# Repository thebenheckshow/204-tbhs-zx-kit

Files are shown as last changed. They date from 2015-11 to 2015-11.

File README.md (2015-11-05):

# 204-tbhs-zx-kit

Ben has modded many old computers into gaming portables and in this episode Ben returns to an old friend - the ZX Spectrum. He gets started by creating a schematic in eagle and designing a small PCB. Ben will conclude his journey in part 2.

Episode 204: Ben Heck's ZX Spectrum 2.0 Part 1 http://www.element14.com/community/docs/DOC-78511/l/episode-204-ben-hecks-zx-spectrum-20-part-1-episode

Episode 206: Ben Heck's ZX Spectrum 2.0 Part 2 http://www.element14.com/community/docs/DOC-78741/l/episode-206-ben-hecks-zx-spectrum-20-part-2-episode

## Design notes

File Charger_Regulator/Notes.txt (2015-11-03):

Regulators on Newark:
http://www.newark.com/Search?catalogId=15003&langId=-1&storeId=10194&gs=true&st=SC4503
http://www.newark.com/webapp/wcs/stores/servlet/Search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

Charger on Newark:
http://www.newark.com/webapp/wcs/stores/servlet/Search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

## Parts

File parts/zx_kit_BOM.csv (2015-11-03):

Part | Value | Device | Package | Description | MF | MPN | OC_FARNELL | OC_NEWARK | PACKAGE | SUPPLIER
32KRAM | CY62256LL-SNXI | CY62256LL-SNXI | SOJ28/3 | 256K (32K x 8) CMOS-Static RAM
32K_ROM | 27C256L | 27C256L | PLCC-32 | CMOS EPROM |  | AT27C256R-70JU | 1095779 | 96K6554
157 | SN74HC157D | SN74HC157D | SO16 | Multiplexer used to select address lines of video RAM
157-1 | SN74HC157D | SN74HC157D | SO16 | Multiplexer used to select address lines of video RAM
BATT |  | MA04-1 | MA04-1 | PIN HEADER |  |  | unknown | unknown
C1 | .1 | C-USC0805 | C0805 | CAPACITOR, American symbol
C2 | .1 | C-USC0805 | C0805 | CAPACITOR, American symbol
C3 | .1 | C-USC0805 | C0805 | CAPACITOR, American symbol
C4 | .1 | C-USC0805 | C0805 | CAPACITOR, American symbol
C5 | 100pf | C-USC0805 | C0805 | CAPACITOR, American symbol
C6 | .1uf | C-USC0805 | C0805 | CAPACITOR, American symbol
C7 | 22nf | C-USC0805 | C0805 | CAPACITOR, American symbol
C8 | 22nf | C-USC0805 | C0805 | CAPACITOR, American symbol
C9 | .1uf | C-USC0805 | C0805 | CAPACITOR, American symbol
C10 | .1uf | C-USC0805 | C0805 | CAPACITOR, American symbol
C11 | 10nf | C-USC0805 | C0805 | CAPACITOR, American symbol
C12 | .1uf | C-USC0805 | C0805 | CAPACITOR, American symbol
C13 | .1uf | C-USC0805 | C0805 | CAPACITOR, American symbol
C14 | 22nf | C-USC0805 | C0805 | CAPACITOR, American symbol
C15 | .1uf | C-USC0805 | C0805 | CAPACITOR, American symbol
C16 | .1uf | C-USC0805 | C0805 | CAPACITOR, American symbol
C17 | 10nf | C-USC0805 | C0805 | CAPACITOR, American symbol
C18 | 33pf | C-USC0805 | C0805 | CAPACITOR, American symbol
C19 | 33pf | C-USC0805 | C0805 | CAPACITOR, American symbol
C20 | 16pf | C-USC0805 | C0805 | CAPACITOR, American symbol
C21 | 150pf | C-USC0805 | C0805 | CAPACITOR, American symbol
C22 | 150pf | C-USC0805 | C0805 | CAPACITOR, American symbol
C23 | 22nf | C-USC0805 | C0805 | CAPACITOR, American symbol
C24 | 47nf | C-USC0805 | C0805 | CAPACITOR, American symbol
C25 | 22uf | CPOL-USB | PANASONIC_B | POLARIZED CAPACITOR, American symbol
C26 | 22nf | C-USC0805 | C0805 | CAPACITOR, American symbol
C27 | 22nf | C-USC0805 | C0805 | CAPACITOR, American symbol
C28 | 10uf | CPOL-USB | PANASONIC_B | POLARIZED CAPACITOR, American symbol
C29 | 22uf | CPOL-USB | PANASONIC_B | POLARIZED CAPACITOR, American symbol
C30 | 22uf | CPOL-USB | PANASONIC_B | POLARIZED CAPACITOR, American symbol
C31 | 10uf | CPOL-USB | PANASONIC_B | POLARIZED CAPACITOR, American symbol
C32 | 15pf | C-USC0805 | C0805 | CAPACITOR, American symbol
C33 | 10uF | CAP_CERAMIC0805 | 0805 | Ceramic Capacitors
C34 | 10uF | CAP_CERAMIC0805 | 0805 | Ceramic Capacitors
D1 |  | DIODE-SOD123 | SOD123 | DIODE
D2 |  | DIODE-SOD123 | SOD123 | DIODE
D3 |  | DIODE-SOD123 | SOD123 | DIODE
D4 |  | DIODE-SOD123 | SOD123 | DIODE
D5 |  | DIODE-SOD123 | SOD123 | DIODE
D6 |  | DIODE-SOD123 | SOD123 | DIODE
D7 |  | DIODE-SOD123 | SOD123 | DIODE
D8 |  | DIODE-SOD123 | SOD123 | DIODE
D9 |  | DIODE-SOD123 | SOD123 | DIODE
D10 |  | DIODE-SOD123 | SOD123 | DIODE
IC1 | 74LS32D | 74LS32D | SO14 | Quad 2-input OR gate
IC3 | 74AC04D | 74AC04D | SO14 | Hex INVERTER
J1 |  | USBMC32599 | MC32599
JP1 |  | AUDIO-JACKPTH | AUDIO-JACK | 3.5mm Audio Jack
JP3 | LOAD_0.1 | HEADER-1X2 | 1X02_OVAL | PIN HEADER
JP5 | BATT_IN_0.1 | HEADER-1X2 | 1X02_OVAL | PIN HEADER
K0 | DTS-6 | DTS-6 | DTS-6
K1 | DTS-6 | DTS-6 | DTS-6
K2 | DTS-6 | DTS-6 | DTS-6
K3 | DTS-6 | DTS-6 | DTS-6
K4 | DTS-6 | DTS-6 | DTS-6
K5 | DTS-6 | DTS-6 | DTS-6
K6 | DTS-6 | DTS-6 | DTS-6
K7 | DTS-6 | DTS-6 | DTS-6
K8 | DTS-6 | DTS-6 | DTS-6
K9 | DTS-6 | DTS-6 | DTS-6
KA | DTS-6 | DTS-6 | DTS-6
KB | DTS-6 | DTS-6 | DTS-6
KC | DTS-6 | DTS-6 | DTS-6
KCAPS | DTS-6 | DTS-6 | DTS-6
KD | DTS-6 | DTS-6 | DTS-6
KE | DTS-6 | DTS-6 | DTS-6
KENT | DTS-6 | DTS-6 | DTS-6
KF | DTS-6 | DTS-6 | DTS-6
KG | DTS-6 | DTS-6 | DTS-6
KH | DTS-6 | DTS-6 | DTS-6
KI | DTS-6 | DTS-6 | DTS-6
KJ | DTS-6 | DTS-6 | DTS-6
KK | DTS-6 | DTS-6 | DTS-6
KL | DTS-6 | DTS-6 | DTS-6
KM | DTS-6 | DTS-6 | DTS-6
KN | DTS-6 | DTS-6 | DTS-6
KO | DTS-6 | DTS-6 | DTS-6
KP | DTS-6 | DTS-6 | DTS-6
KQ | DTS-6 | DTS-6 | DTS-6
KR | DTS-6 | DTS-6 | DTS-6
KS | DTS-6 | DTS-6 | DTS-6
KSPACE | DTS-6 | DTS-6 | DTS-6
KSYM | DTS-6 | DTS-6 | DTS-6
KT | DTS-6 | DTS-6 | DTS-6
KU | DTS-6 | DTS-6 | DTS-6
KV | DTS-6 | DTS-6 | DTS-6
KW | DTS-6 | DTS-6 | DTS-6
KX | DTS-6 | DTS-6 | DTS-6
KY | DTS-6 | DTS-6 | DTS-6
KZ | DTS-6 | DTS-6 | DTS-6
LED1 | STAT1-ORANGE | LED0805 | CHIPLED_0805 | LED
LED2 | STAT2-GREEN | LED0805 | CHIPLED_0805 | LED
LED3 | Power-RED | LED0805 | CHIPLED_0805 | LED
Q1 | 14MHz | CRYSTALCTS406 | CTS406 | CRYSTAL |  |  | unknown | unknown
Q2 | 4.43MHz | CRYSTALHC49S | HC49/S | CRYSTAL |  |  | 1667008 | unknown
R1 | 470 | R-US_M0805 | M0805 | RESISTOR, American symbol
R2 | 470 | R-US_M0805 | M0805 | RESISTOR, American symbol
R3 | 470 | R-US_M0805 | M0805 | RESISTOR, American symbol
R4 | 470 | R-US_M0805 | M0805 | RESISTOR, American symbol
R5 | 470 | R-US_M0805 | M0805 | RESISTOR, American symbol
R6 | 470 | R-US_M0805 | M0805 | RESISTOR, American symbol
R7 | 470 | R-US_M0805 | M0805 | RESISTOR, American symbol
R8 | 470 | R-US_M0805 | M0805 | RESISTOR, American symbol
R9 | 8K2 | R-US_M0805 | M0805 | RESISTOR, American symbol
R10 | 8K2 | R-US_M0805 | M0805 | RESISTOR, American symbol
R11 | 8K2 | R-US_M0805 | M0805 | RESISTOR, American symbol
R12 | 8K2 | R-US_M0805 | M0805 | RESISTOR, American symbol
R13 | 8K2 | R-US_M0805 | M0805 | RESISTOR, American symbol
R14 | 8K2 | R-US_M0805 | M0805 | RESISTOR, American symbol
R15 | 8K2 | R-US_M0805 | M0805 | RESISTOR, American symbol
R16 | 8K2 | R-US_M0805 | M0805 | RESISTOR, American symbol
R17 | 680 | R-US_M0805 | M0805 | RESISTOR, American symbol
R18 | 680 | R-US_M0805 | M0805 | RESISTOR, American symbol
R19 | 680 | R-US_M0805 | M0805 | RESISTOR, American symbol
R20 | 680 | R-US_M0805 | M0805 | RESISTOR, American symbol
R21 | 10k | R-US_R0805 | R0805 | RESISTOR, American symbol
R22 | 680 | R-US_M0805 | M0805 | RESISTOR, American symbol
R23 | 680 | R-US_M0805 | M0805 | RESISTOR, American symbol
R24 | 680 | R-US_M0805 | M0805 | RESISTOR, American symbol
R25 | 330 | R-US_M0805 | M0805 | RESISTOR, American symbol
R26 | 10k | R-US_R0805 | R0805 | RESISTOR, American symbol
R27 | 10k | R-US_R0805 | R0805 | RESISTOR, American symbol
R28 | 10k | R-US_R0805 | R0805 | RESISTOR, American symbol
R29 | 10k | R-US_R0805 | R0805 | RESISTOR, American symbol
R30 | 1k | R-US_R0805 | R0805 | RESISTOR, American symbol
R31 | 180 | R-US_R0805 | R0805 | RESISTOR, American symbol
R32 | 1k | R-US_R0805 | R0805 | RESISTOR, American symbol
R33 | 470 | R-US_R0805 | R0805 | RESISTOR, American symbol
R34 | 150 | RESISTOR0805 | 0805 | Resistors
R35 | 10k | R-US_R0805 | R0805 | RESISTOR, American symbol
R36 | 680 | R-US_R0805 | R0805 | RESISTOR, American symbol
R37 | 1k | R-US_R0805 | R0805 | RESISTOR, American symbol
R38 | 10k | R-US_R0805 | R0805 | RESISTOR, American symbol
R39 | 10k | R-US_R0805 | R0805 | RESISTOR, American symbol
R40 | 470 | R-US_R0805 | R0805 | RESISTOR, American symbol
R41 | 1k | R-US_R0805 | R0805 | RESISTOR, American symbol
R42 | 1k | R-US_R0805 | R0805 | RESISTOR, American symbol
R43 | 1k | R-US_R0805 | R0805 | RESISTOR, American symbol
R44 | 1k | R-US_R0805 | R0805 | RESISTOR, American symbol
R45 | 5k1 | R-US_R0805 | R0805 | RESISTOR, American symbol
R46 | 3k | R-US_R0805 | R0805 | RESISTOR, American symbol
R47 | 1k | R-US_R0805 | R0805 | RESISTOR, American symbol
R48 | 1k | R-US_R0805 | R0805 | RESISTOR, American symbol
R49 | 1k | R-US_R0805 | R0805 | RESISTOR, American symbol
R50 | 1k | R-US_R0805 | R0805 | RESISTOR, American symbol
R51 | 10K | R-US_R0805 | R0805 | RESISTOR, American symbol
R52 | 15 | R-US_R0805 | R0805 | RESISTOR, American symbol
R53 | 2k2 | R-US_R0805 | R0805 | RESISTOR, American symbol
R54 | 2k2 | R-US_R0805 | R0805 | RESISTOR, American symbol
R55 | 390 | R-US_R0805 | R0805 | RESISTOR, American symbol
R56 | 4k7 | R-US_R0805 | R0805 | RESISTOR, American symbol
R57 | 2k2 | R-US_R0805 | R0805 | RESISTOR, American symbol
R58 | 10k | R-US_R0805 | R0805 | RESISTOR, American symbol
R59 | 220k | R-US_M0805 | M0805 | RESISTOR, American symbol
R60 | 1k5 | R-US_M0805 | M0805 | RESISTOR, American symbol
R61 | 10k | R-US_M0805 | M0805 | RESISTOR, American symbol
R62 | 1k | R-US_M0805 | M0805 | RESISTOR, American symbol
R63 | 150 | RESISTOR0805 | 0805 | Resistors
R64 | 470 | R-US_R0805 | R0805 | RESISTOR, American symbol
R65 | 15 | R-US_R1210 | R1210 | RESISTOR, American symbol
R66 | 150 | RESISTOR0805 | 0805 | Resistors
R67 | PROG | RESISTOR_DUAL | 0805-THM | Flip Flop resistor
R68 | 10K/THERM | R-US_FLIPFLOP | 0805-THM | RESISTOR, American symbol
REGS |  | MA04-1 | MA04-1 | PIN HEADER |  |  | unknown | unknown
ROMS |  | PINHD-1X3 | 1X03 | PIN HEADER
RST | DTS-6 | DTS-6 | DTS-6
RT1 | 1K | R-US_R0805 | R0805 | RESISTOR, American symbol
RT2 | 150K | R-US_R0805 | R0805 | RESISTOR, American symbol
SPKR |  | PINHD-1X2 | 1X02 | PIN HEADER
T1 | BC847 | BC847 | SOT23 | NPN TRANSISTOR
T2 | 4401 | MMBT4401LT1-NPN-SOT23-BEC | SOT23-BEC | NPN Transistror
T3 | 4401 | MMBT4401LT1-NPN-SOT23-BEC | SOT23-BEC | NPN Transistror
T4 | BC847 | BC847 | SOT23 | NPN TRANSISTOR
T5 | 4401 | MMBT4401LT1-NPN-SOT23-BEC | SOT23-BEC | NPN Transistror
T6 | 4401 | MMBT4401LT1-NPN-SOT23-BEC | SOT23-BEC | NPN Transistror
T7 | 4401 | MMBT4401LT1-NPN-SOT23-BEC | SOT23-BEC | NPN Transistror
U$1 | MC74HC574A | MC74HC574A | SO20W | Octal 3-State Noninverting D Flip Flop
U$2 | LM1889 | LM1889 | SOCKET-18 | LM1889 TV Video Modulator
U$3 | MS12ASW30_01 | MS12ASW30_01 | MS12ASG30_01
U1 | MCP73833-FCI/UN | MCP73833-FCI/UN | SOP50P490X110-10N | LI-ION/LI-POLY CONTROLLERS |  | MCP73833-FCI/UN | 1605576 | 88K5666 | MSOP10 | Microchip
ULA |  | ZXULA | DIL40 | ZX Spectrum Custom ULA
ULA_RAM | CY62256LL-SNXI | CY62256LL-SNXI | SOJ28/3 | 256K (32K x 8) CMOS-Static RAM
VID |  | PINHD-1X2 | 1X02 | PIN HEADER
VPOW |  | PINHD-1X2 | 1X02 | PIN HEADER
Z80A |  | Z80CPU | DIL40 | Z80 FAMILY DEVICE

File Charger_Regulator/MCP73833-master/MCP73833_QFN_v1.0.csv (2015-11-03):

Check | Qty | Value | Device | Package | Parts | Description
 | 1 | MCP73833T-AMI/MF | MCP73833DFN | DFN10_3X3MM | U1 | Lithium-Polymer/Lithium-Ion Battery Charger [Part No.]
 | 4 | MOUNTINGHOLE2.0 | MOUNTINGHOLE2.0 | MOUNTINGHOLE_2.0_PLATED | U$11, U$16, U$18, U$19 | Mounting Hole
x | 1 | 150K | R-US_R0805 | R0805 | RT2 | RESISTOR, American symbol
x | 1 | 1K | R-US_R0805 | R0805 | RT1 | RESISTOR, American symbol
x | 1 | 10K/THERM | R-US_FLIPFLOP | 0805-THM | R7 | RESISTOR, American symbol
x | 1 | PROG | RESISTOR_DUAL | 0805-THM | R4 | Flip Flop resistor
x | 3 | 150 | RESISTOR0805 | 805 | R1, R2, R3 | Resistors
UK | 1 | Power-RED | LED0805 | CHIPLED_0805 | LED3 | LED
UK | 1 | STAT2-GREEN | LED0805 | CHIPLED_0805 | LED2 | LED
UK | 1 | STAT1-ORANGE | LED0805 | CHIPLED_0805 | LED1 | LED
 | 1 | STAT | HEADER-1X2 | 1X02_OVAL | JP6 | PIN HEADER
 | 1 | BATT_IN_0.1 | HEADER-1X2 | 1X02_OVAL | JP5 | PIN HEADER
 | 1 | LOAD_0.1 | HEADER-1X2 | 1X02_OVAL | JP3 | PIN HEADER
 | 2 | FIDUCIAL1.5X3 | FIDUCIAL1X2.5 | FIDUCIAL-1X2.5 | JP2, JP4 | Fiducial Alignment Points
 | 1 | PWR_IN_0.1 | HEADER-1X2 | 1X02_OVAL | JP1 | PIN HEADER
 | 1 | LOAD_JST | JST_2PIN | JSTPH2 | CN3 | JST 2-Pin Right-Angle Connector
 | 1 | BATT_IN_JST | JST_2PIN | JSTPH2 | CN2 | JST 2-Pin Right-Angle Connector
 | 1 | USB | USBMINIBLARGE | USB-MINIB_LARGER | CN1 | USB Connectors
 | 2 | 10uF | CAP_CERAMIC0805 | 805 | C1, C2 | Ceramic Capacitors

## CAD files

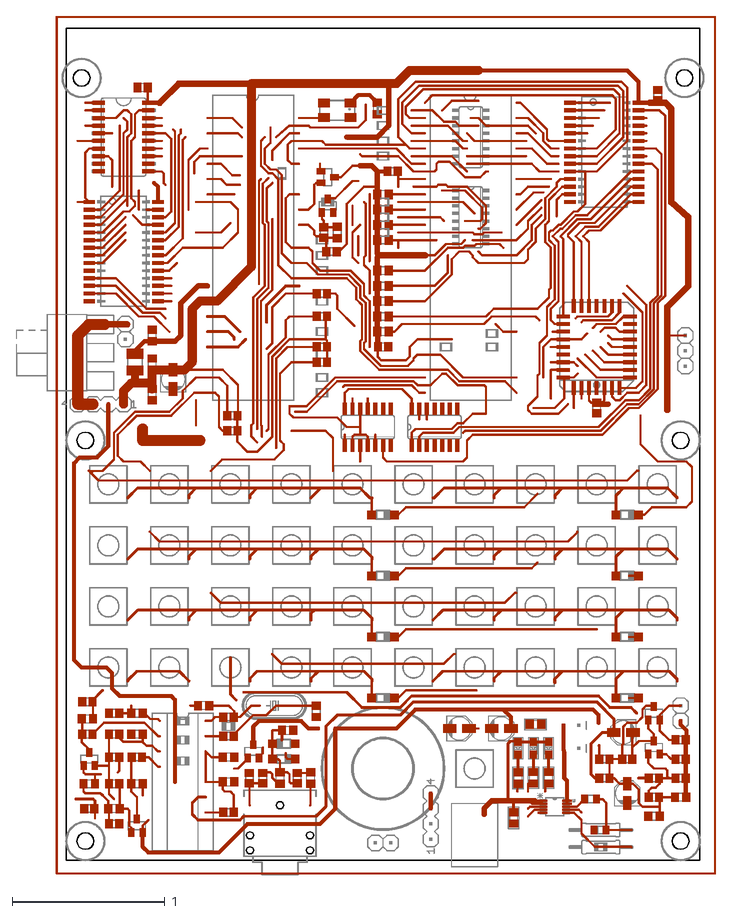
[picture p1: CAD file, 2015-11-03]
Board/zx_kit3.dxf
4.58 x 5.63

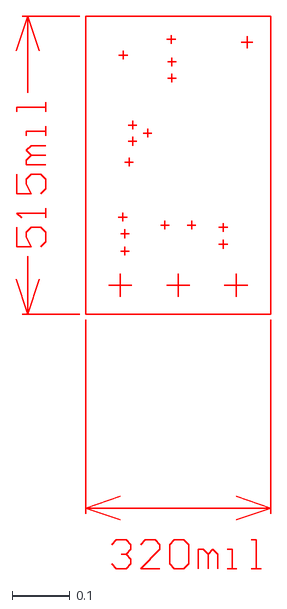
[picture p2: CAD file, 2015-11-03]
Charger_Regulator/12VRegulator/reg10a01-drill.dxf
0.44 x 0.955

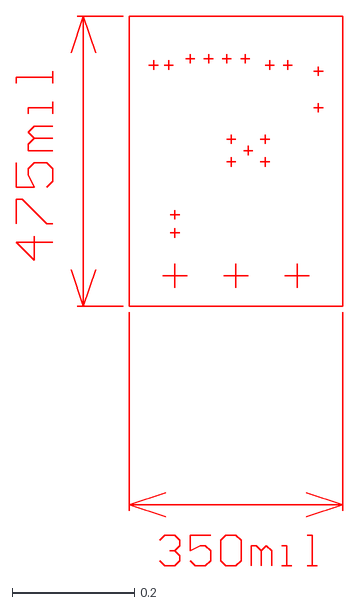
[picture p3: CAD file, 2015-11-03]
Charger_Regulator/5VRegulator/reg09a01-drill.dxf
0.535 x 0.9

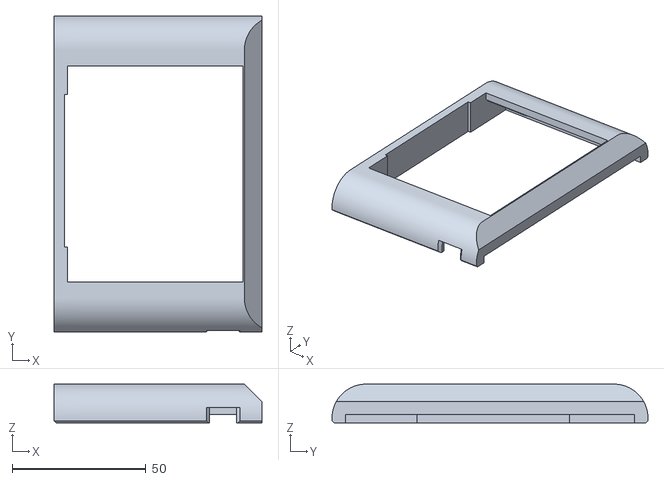
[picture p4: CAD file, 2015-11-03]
Enclosure/STL/front LCD riser.stl
77.6 x 118.1 x 14.5

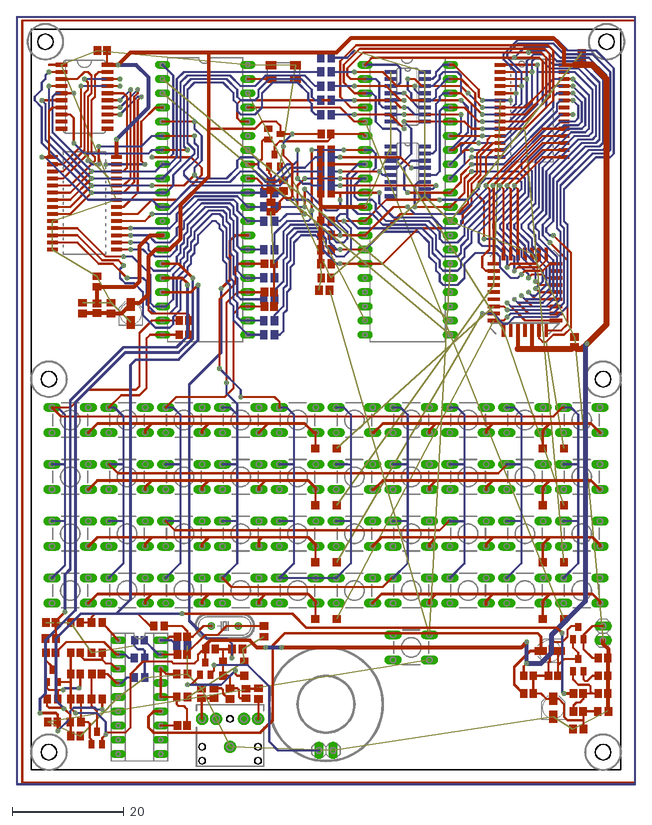
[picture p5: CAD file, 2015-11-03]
Enclosure/zx_kit2.dxf
110.8 x 137.5

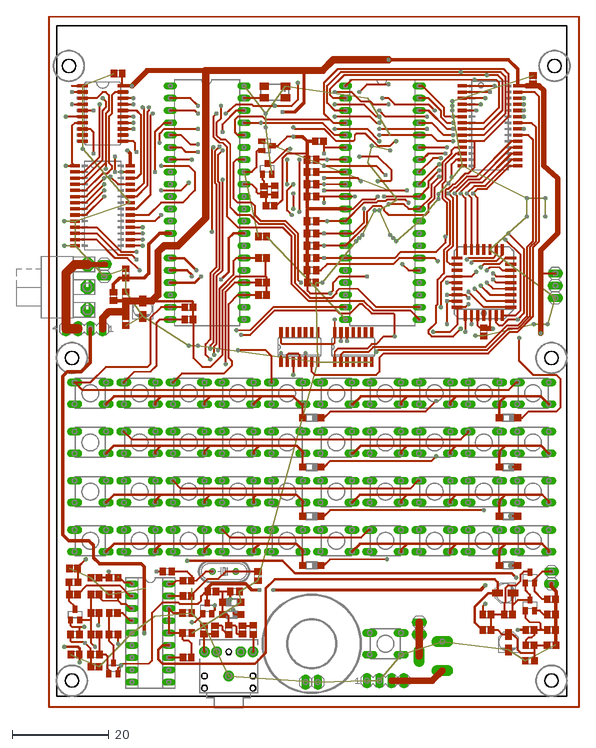
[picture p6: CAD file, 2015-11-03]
Board/zx_kit2.dxf
116.5 x 143.0

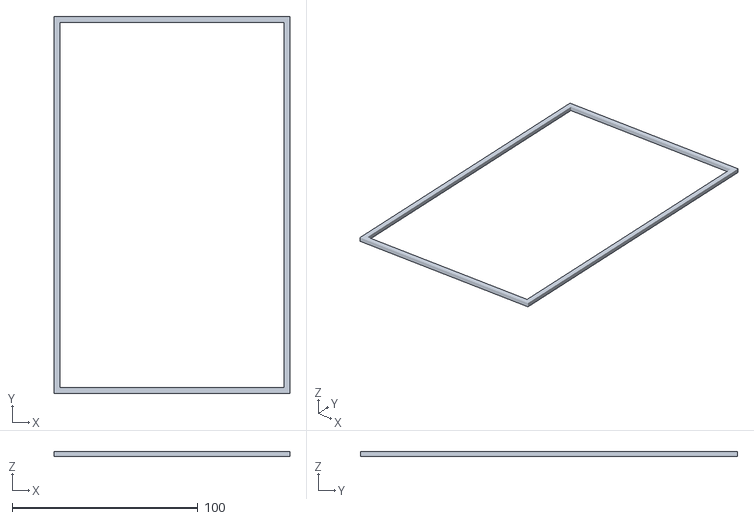
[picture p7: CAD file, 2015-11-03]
Enclosure/STL/wrecktangle.stl
127.0 x 203.2 x 2.54

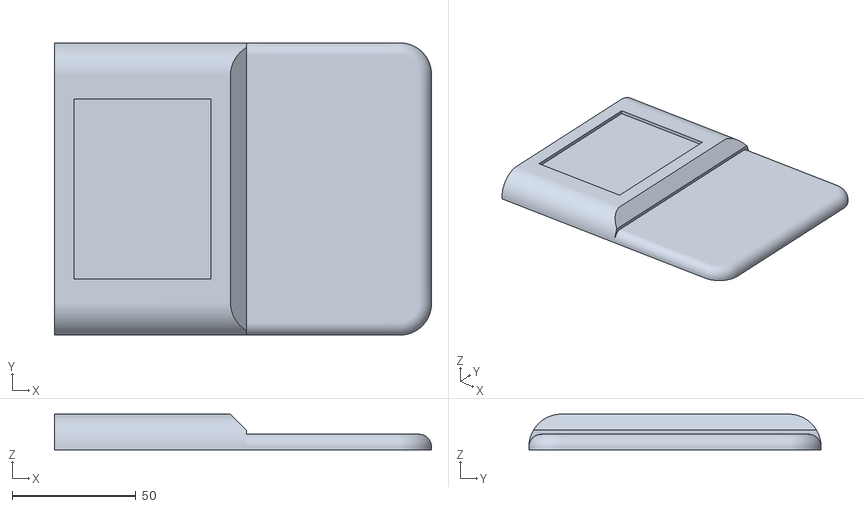
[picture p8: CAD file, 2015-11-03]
Enclosure/STL/front test.stl
152.4 x 118.1 x 14.5

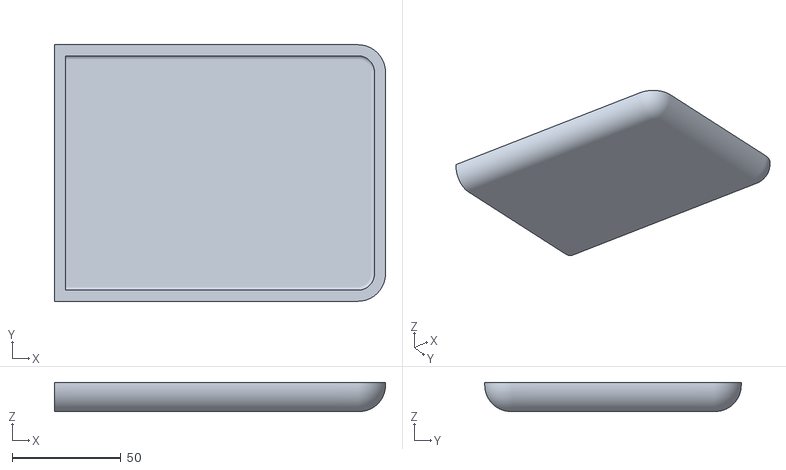
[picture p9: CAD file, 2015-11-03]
Enclosure/STL/back test.stl
152.4 x 118.1 x 13.4

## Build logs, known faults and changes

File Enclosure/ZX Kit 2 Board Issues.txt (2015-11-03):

PROBLEM: MREQ net labeled "MREQL" on CPU/ULA but "MREQ" on OR gate.
RESULT: Missing connection between CPU and OR gate on board casuing upper RAM conflict
SOLUTION: Bridge MREQ from CPU to OR gate.

PROBLEM: IORQ on CPU not connected to anything.
RESULT: Can't read keyboard from ULA (and would cause other issues too)
SOLUTION: Added a 470 ohm resister and wire between CPU's IOREQ and ULA's IOREQ (rest of circuit was placed correctly just missed this connection)

PROBLEM: INTL on ULA not connected to anything.
RESULT: System doesn't work
SOLUTION: Added a 470 ohm resister and wire between CPU's INT and ULA's INT

PROBLEM: Jumbled text on screen as a result of address bus conflict
SOLUTION: Between the MUX and ULA, use 680 ohm resisters instead of 330 (470 may work as well)

PROBLEM: ROM CE not connected to anything
RESULT: ROM doesn't work right.
SOLUTION:
OR the CPU's MREQ and the ULA's ROM_CS (through 600 ohm resistor) together, send result to ROM CE
Connect ROM_OE to CPU's READ instead of ROM_CS (move the resistor) 

NEED TO CHECK TAPE LOADING NEXT!

NEED TO ADD / CHANGE:

DONE - Remove 2k pullup on CASS/SPEAKER line to enable modern "tape" loading

DONE - Move (2) 10k resisters out from under ULA!

DONE - 15pf cap on ground side of 14MHz crystal

DONE - 1/2 watt 15 ohm thick film resistor for ULA VCC SMD case style 1210

DONE - 10uf ELEC cap on reset button for system start

DONE - ELEC CAP on lower 5v rail for speaker compensation

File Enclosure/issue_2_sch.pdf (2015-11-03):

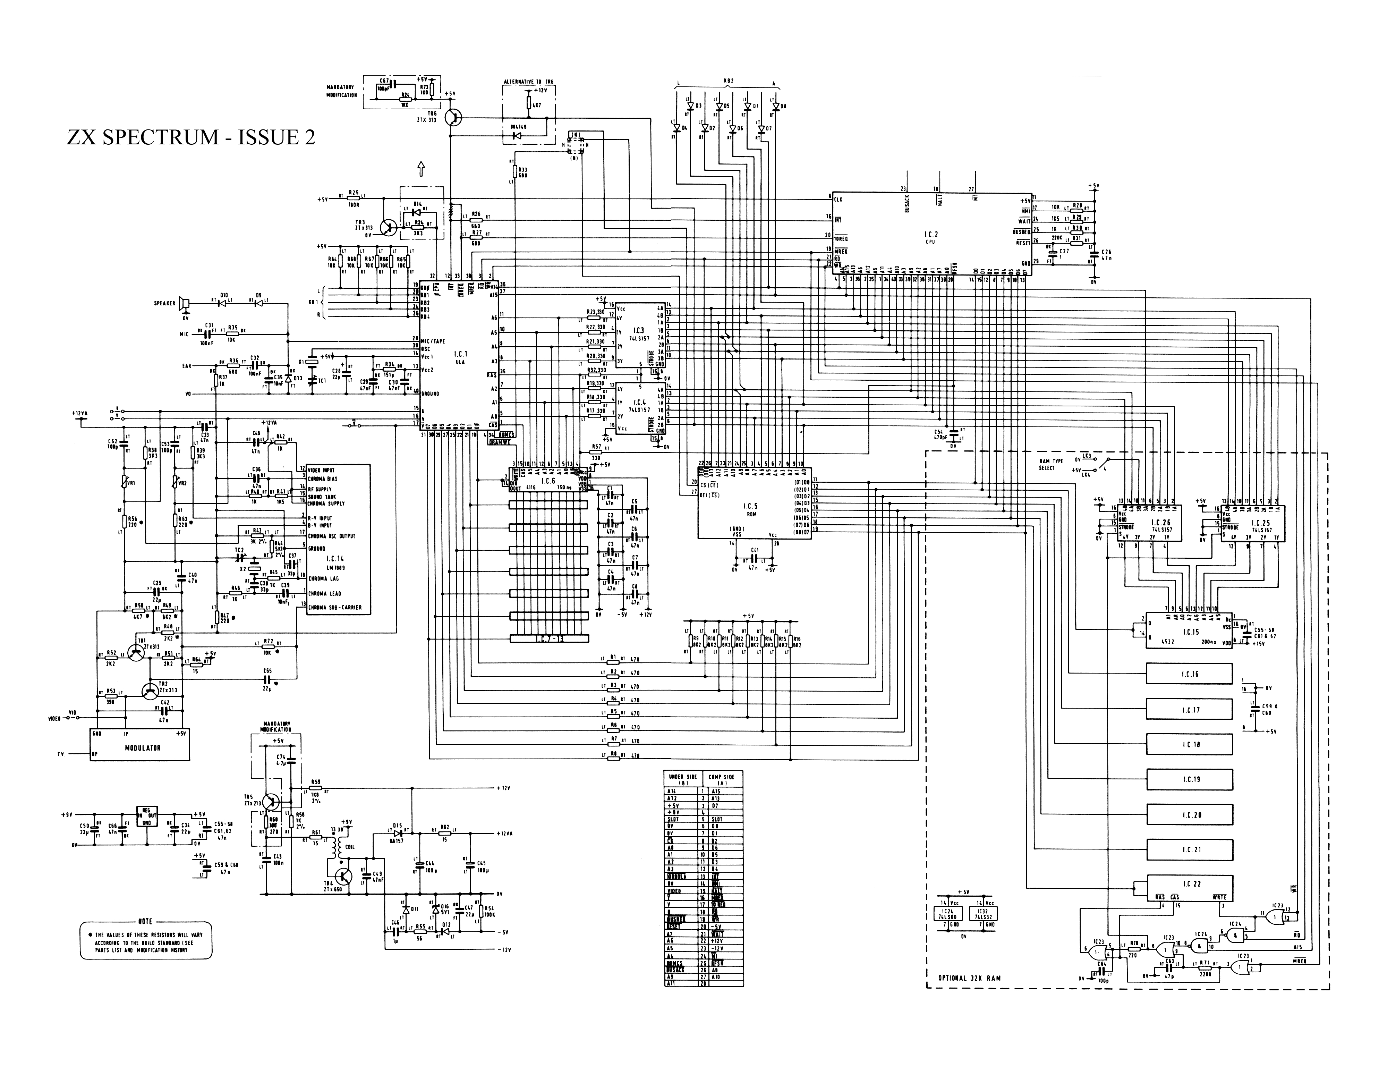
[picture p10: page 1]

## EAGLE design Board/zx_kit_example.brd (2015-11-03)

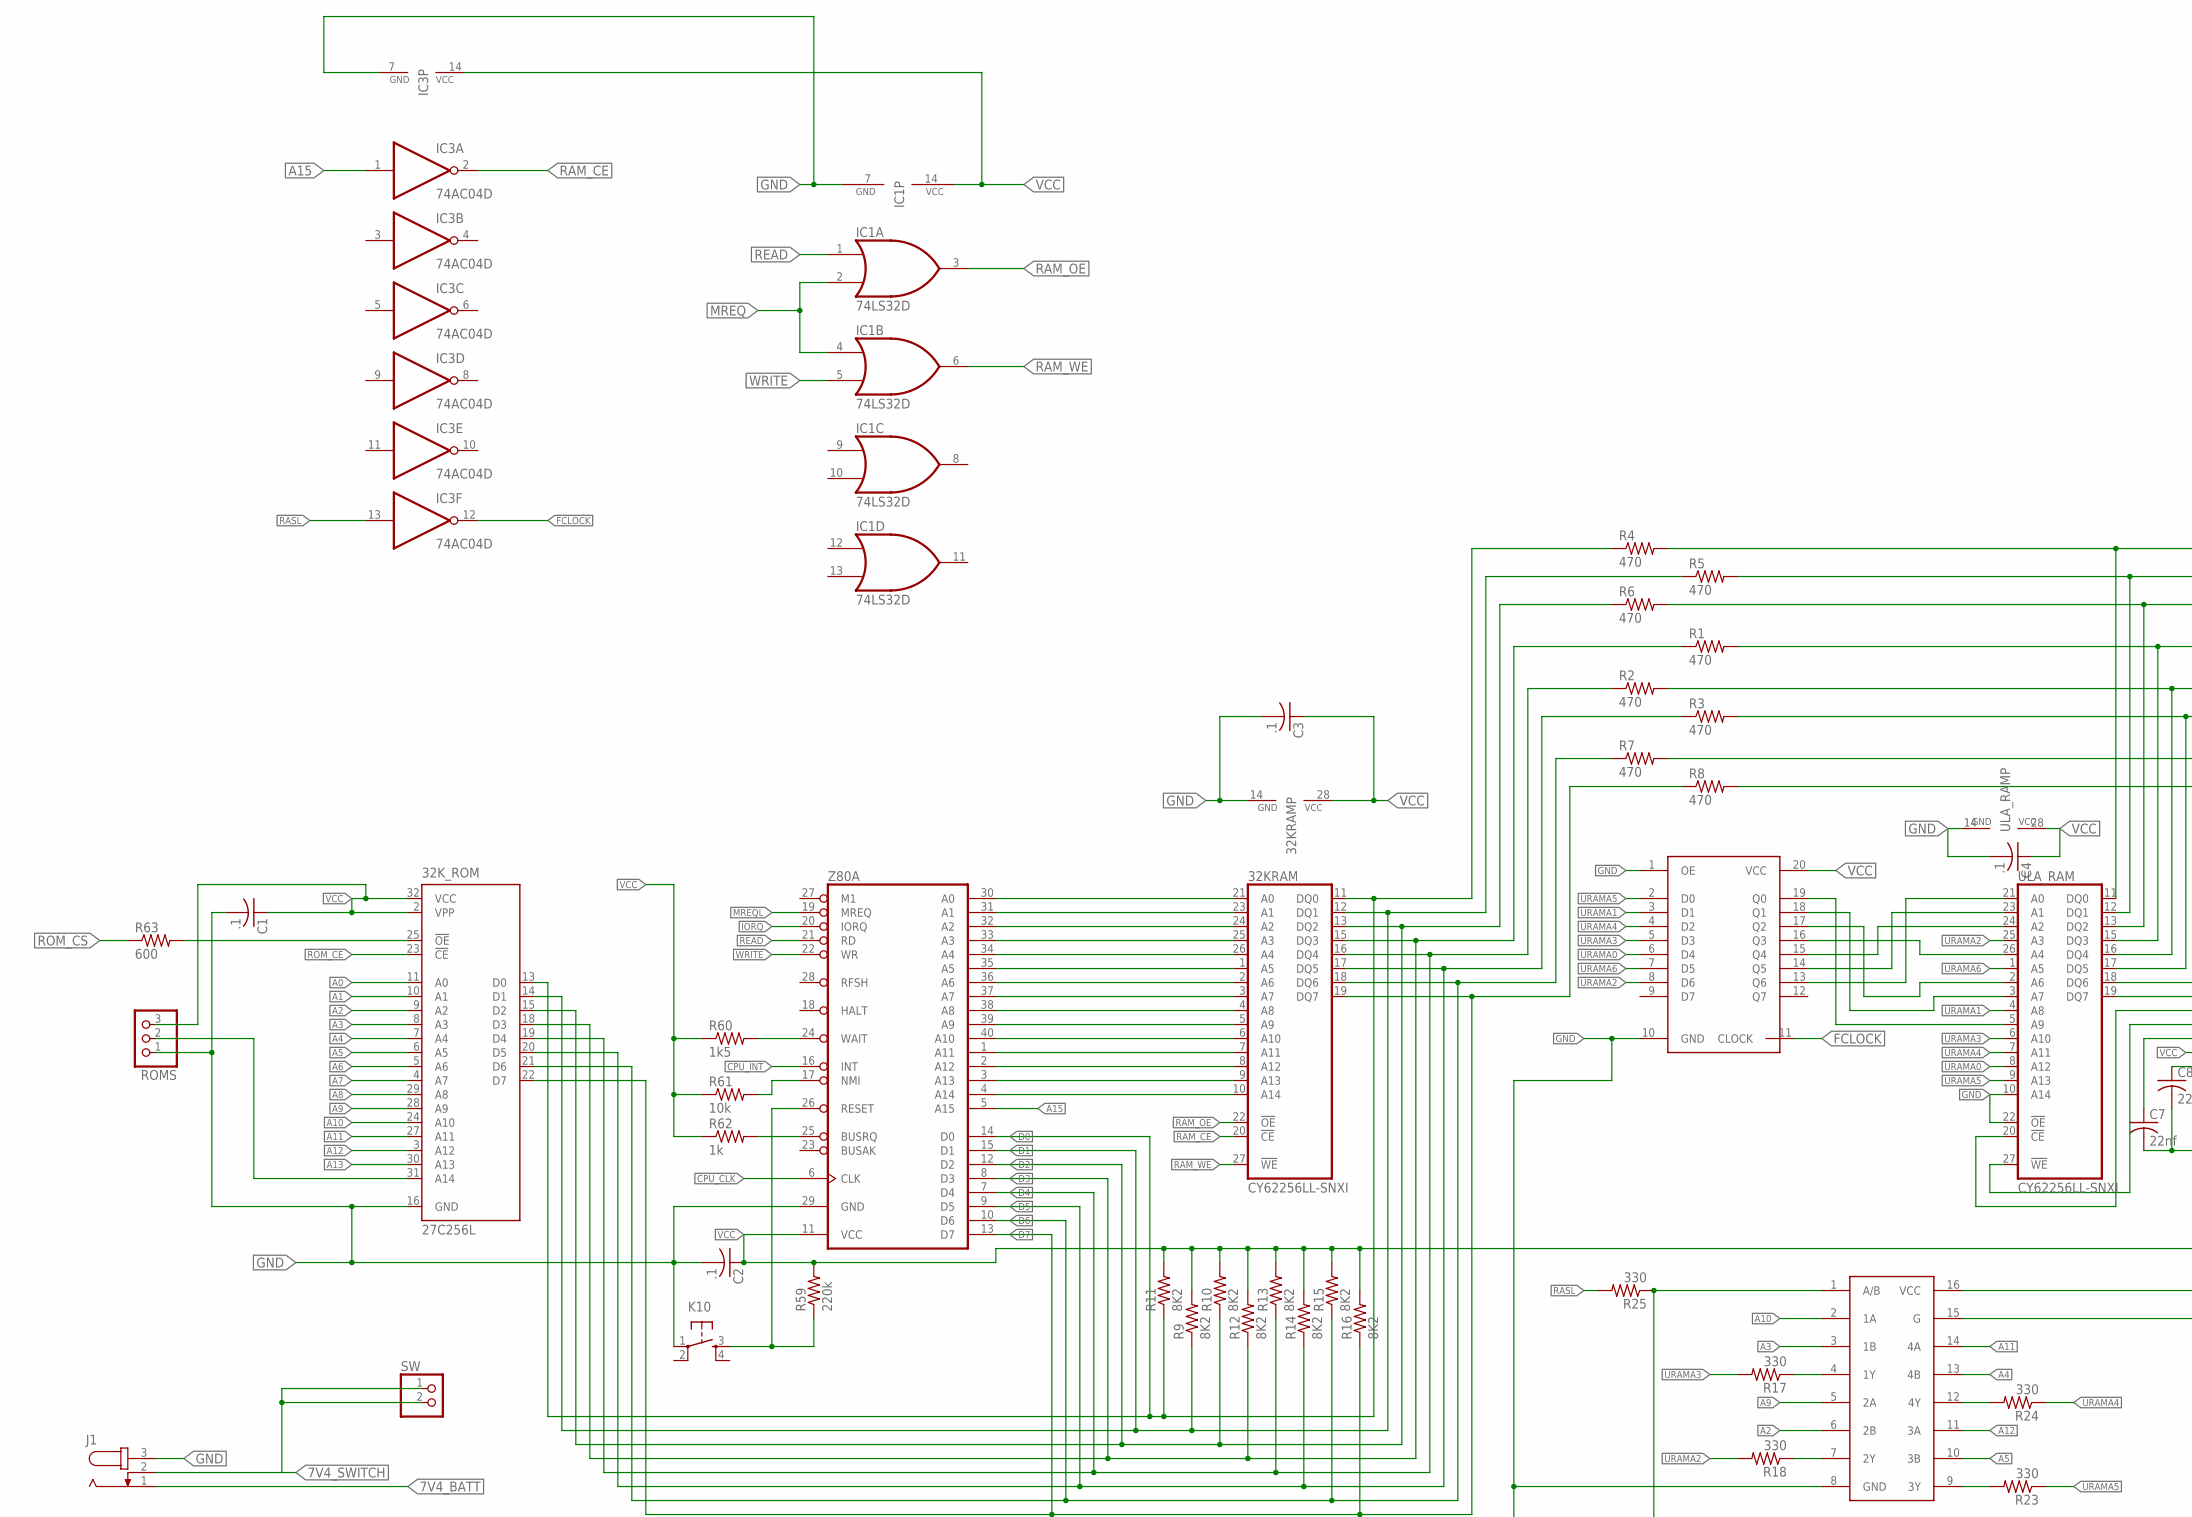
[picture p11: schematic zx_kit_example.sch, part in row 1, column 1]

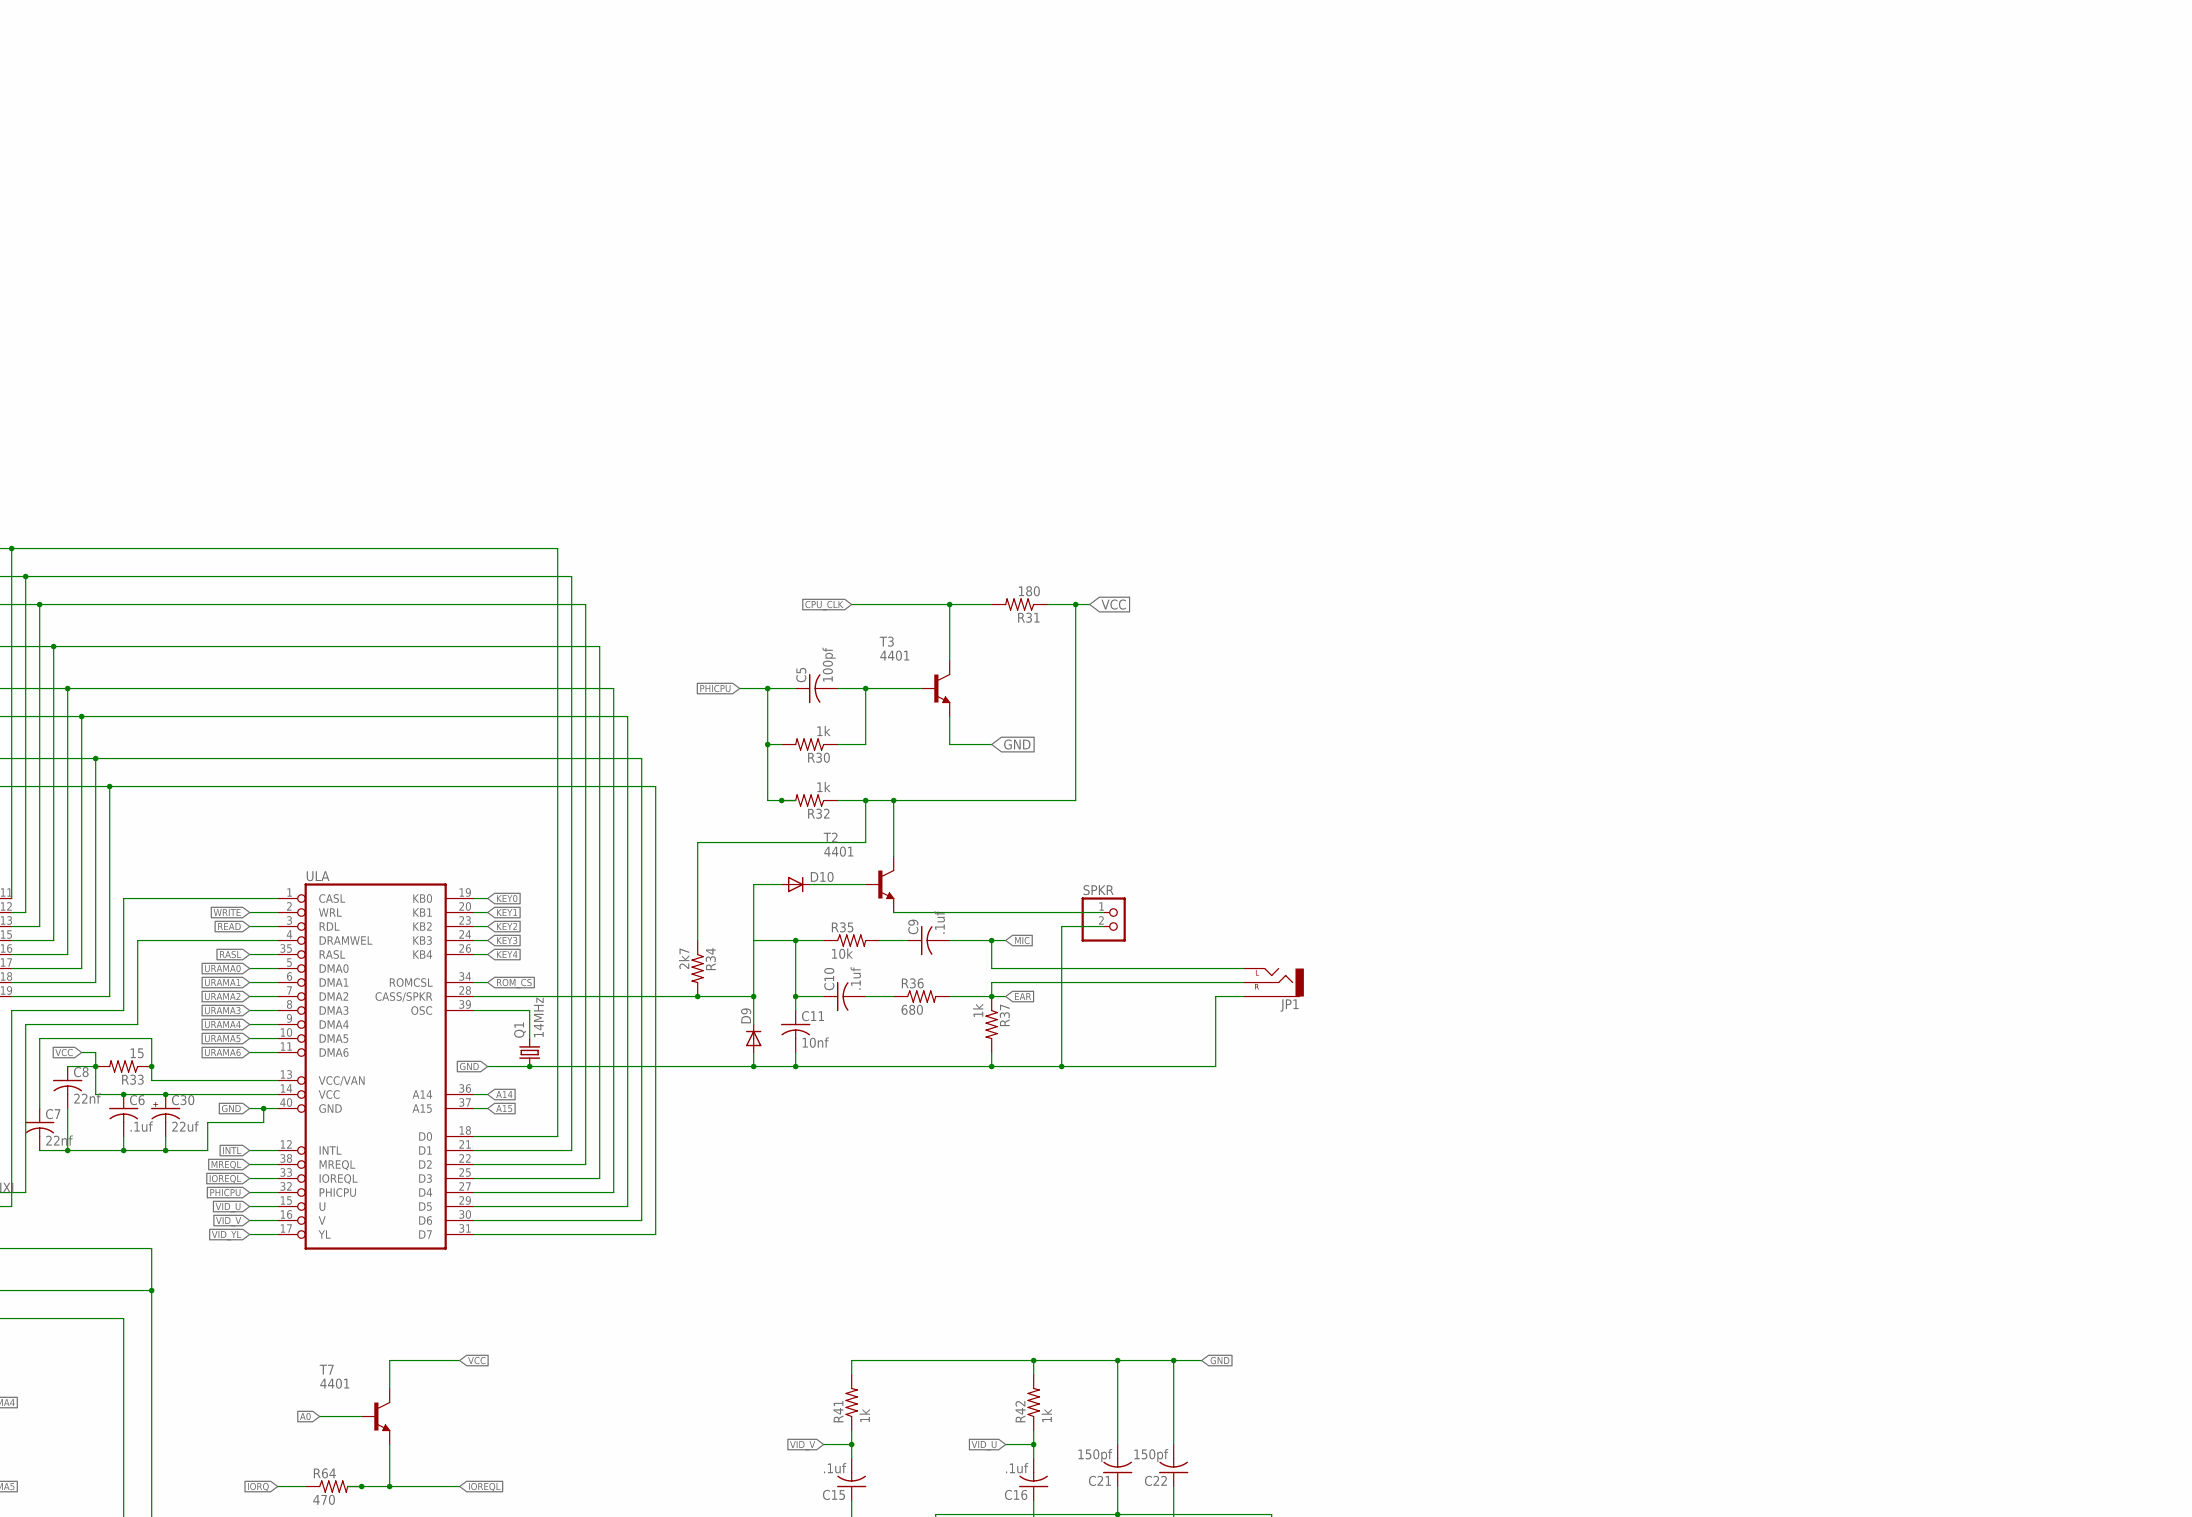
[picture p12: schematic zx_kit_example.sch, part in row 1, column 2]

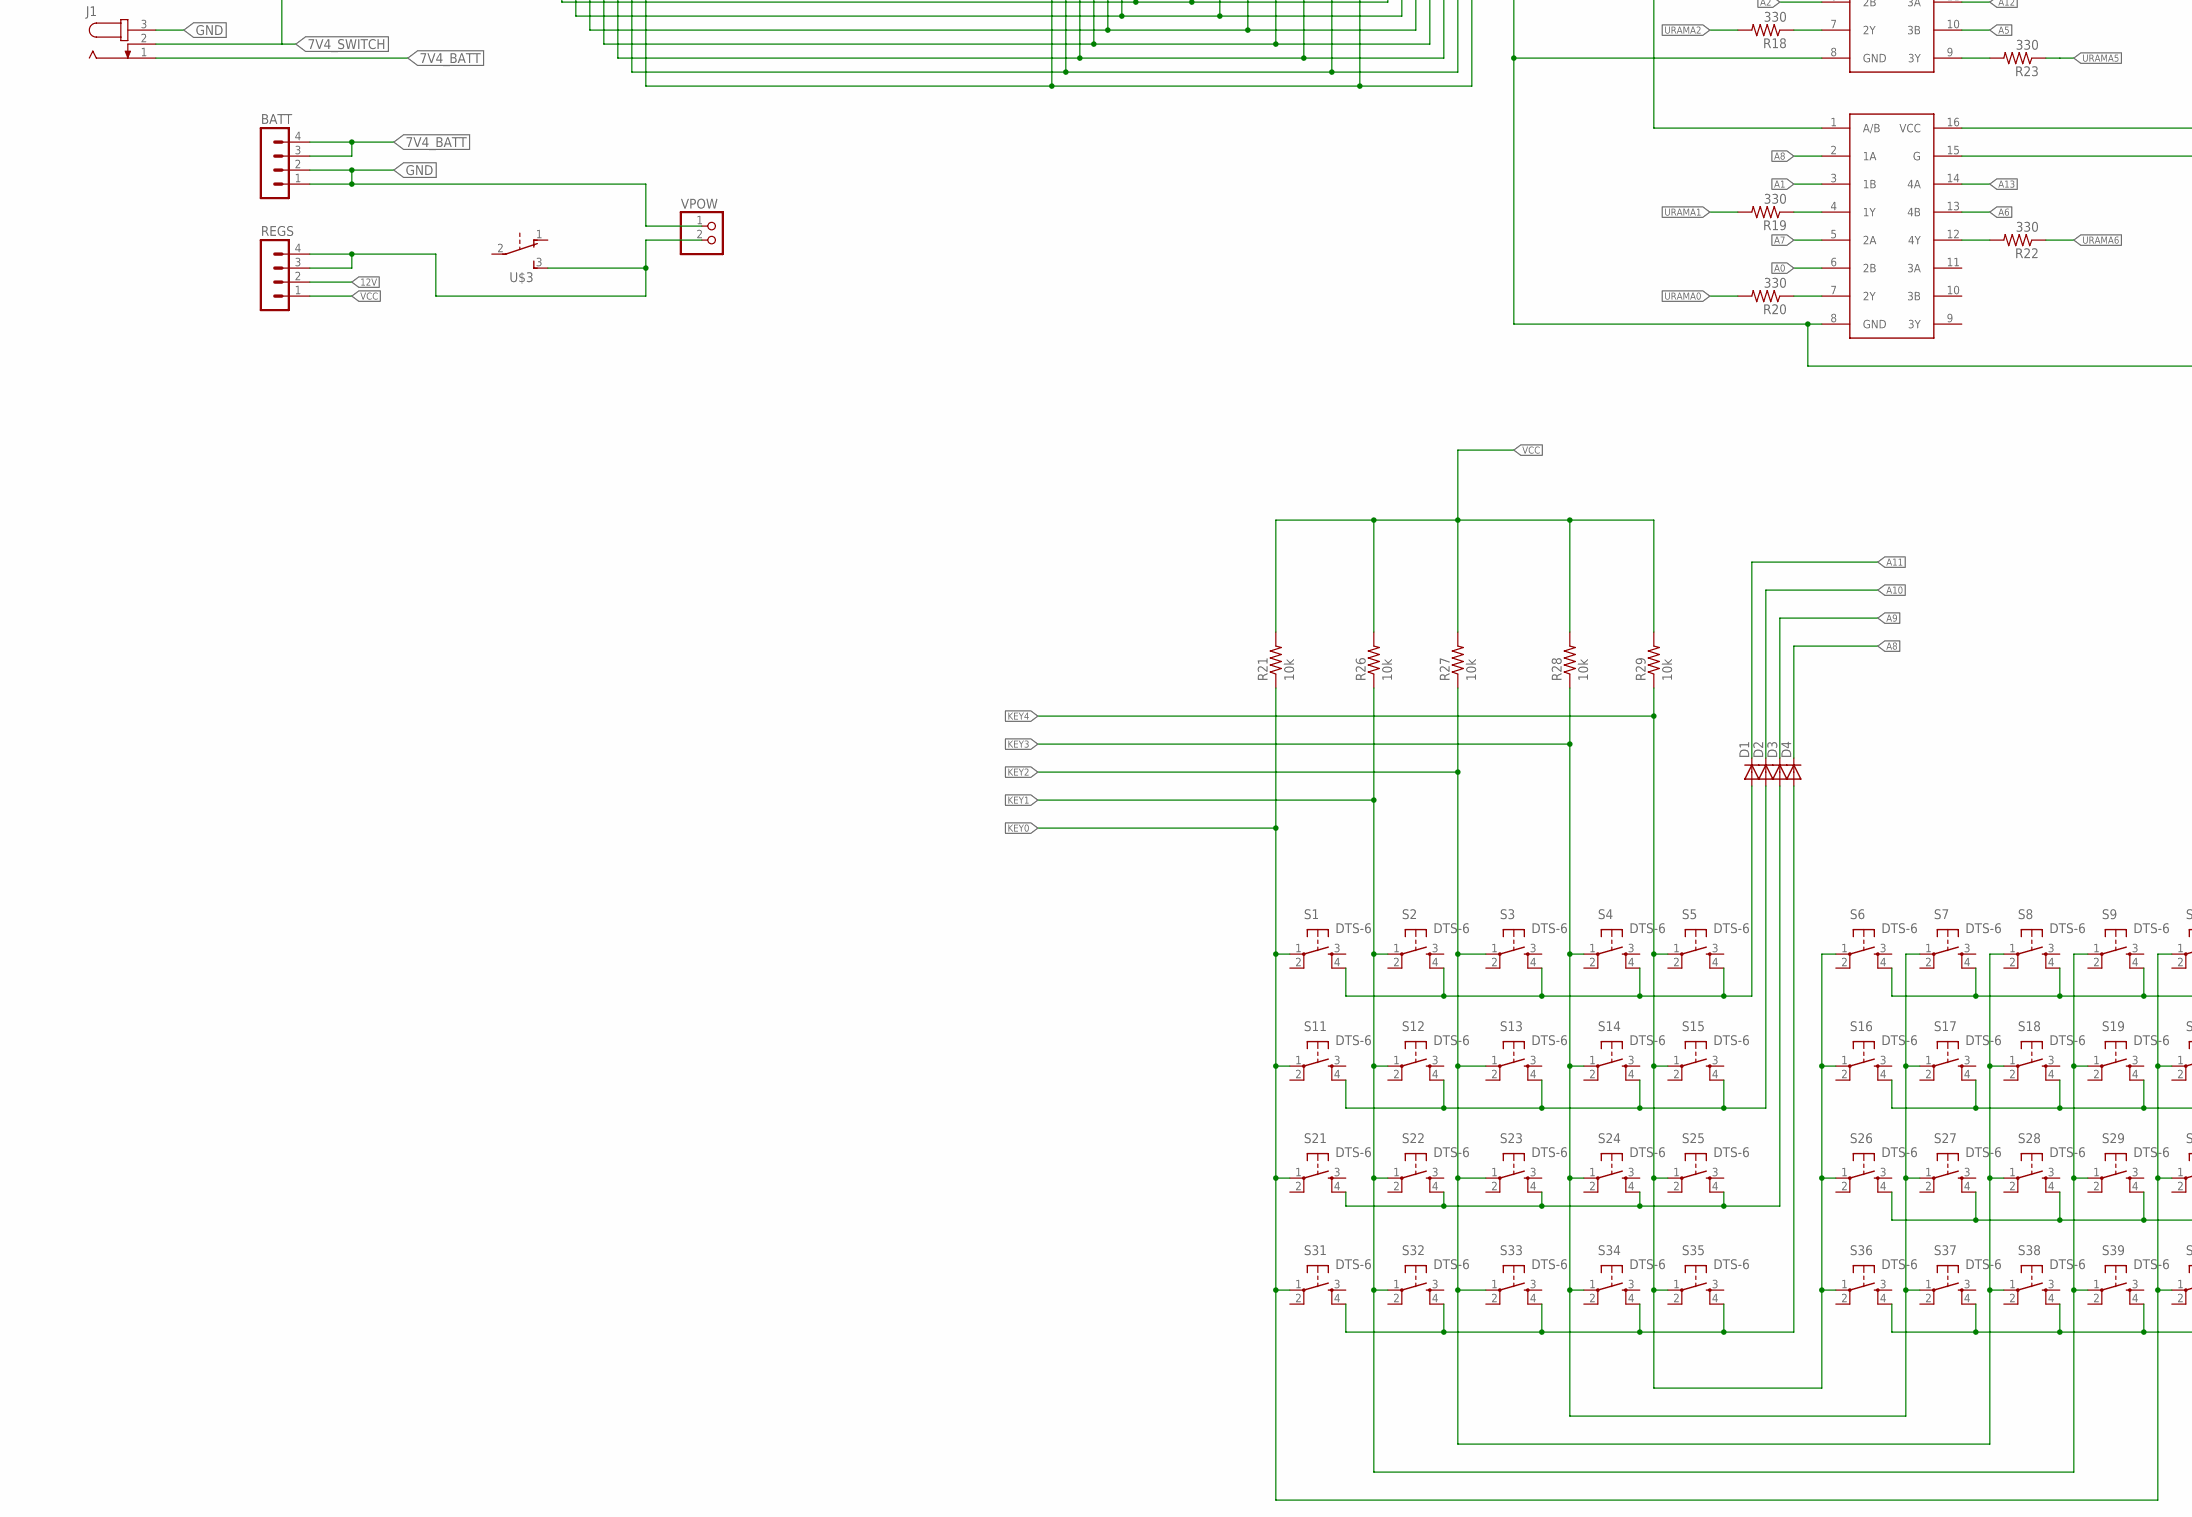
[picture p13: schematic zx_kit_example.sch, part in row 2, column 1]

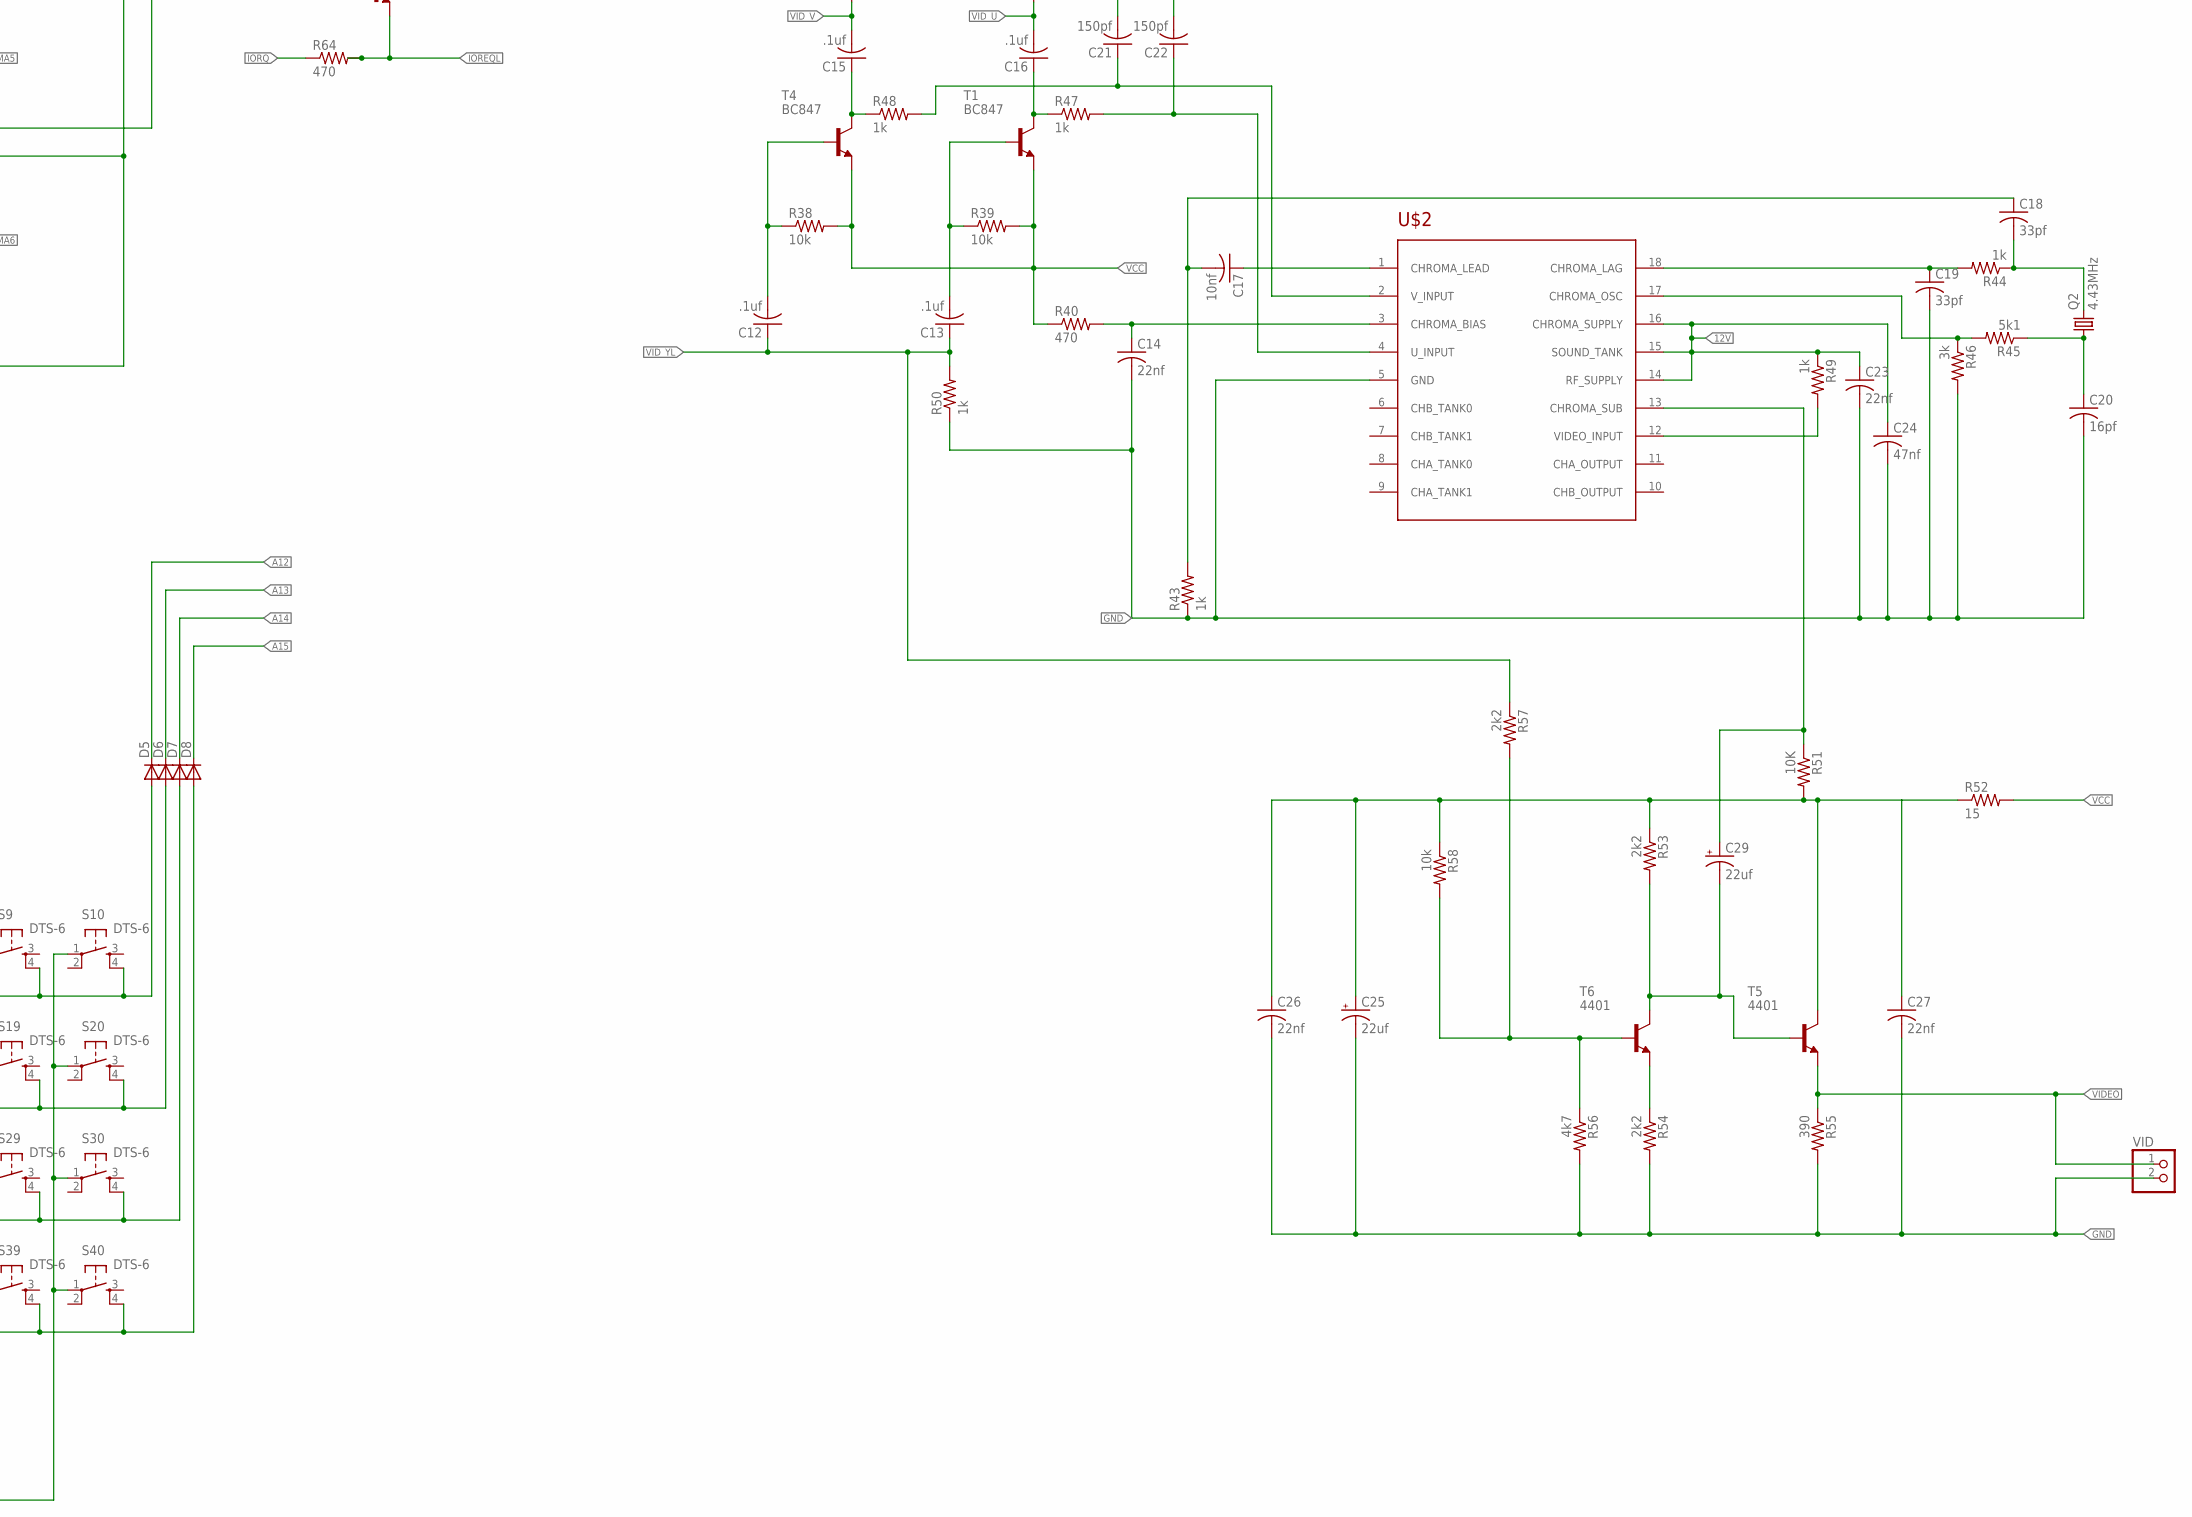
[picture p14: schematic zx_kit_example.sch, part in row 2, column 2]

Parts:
32KRAM: CY62256LL-SNXI; SOJ28/3
32K_ROM: 27C256L; PLCC-32
157, 157-1: SN74HC157D; SO16
BATT: MA04-1
C1, C2, C3, C4: .1; C0805
C5: 100pf; C0805
C6, C9, C10, C12, C13, C15, C16: .1uf; C0805
C7, C8, C14, C23, C26, C27: 22nf; C0805
C11, C17: 10nf; C0805
C18, C19: 33pf; C0805
C20: 16pf; C0805
C21, C22: 150pf; C0805
C24: 47nf; C0805
C25, C29, C30: 22uf; PANASONIC_B
D1, D2, D3, D4, D5, D6, D7, D8, D9, D10: DIODE-SOD123; SOD123
IC1: 74LS32D; SO14
IC3: 74AC04D; SO14
J1: JACK-PLUG0; SPC4077
JP1: AUDIO-JACKPTH; AUDIO-JACK
K10: DTS-6
Q1: 14MHz; CTS406
Q2: 4.43MHz; HC49/S
R1, R2, R3, R4, R5, R6, R7, R8: 470; M0805
R9, R10, R11, R12, R13, R14, R15, R16: 8K2; M0805
R17, R18, R19, R20, R22, R23, R24, R25: 330; M0805
R21, R26, R27, R28, R29, R35, R38, R39, R58: 10k; R0805
R30, R32, R37, R41, R42, R43, R44, R47, R48, R49, R50: 1k; R0805
R31: 180; R0805
R33, R52: 15; R0805
R34: 2k7; R0805
R36: 680; R0805
R40, R64: 470; R0805
R45: 5k1; R0805
R46: 3k; R0805
R51: 10K; R0805
R53, R54, R57: 2k2; R0805
R55: 390; R0805
R56: 4k7; R0805
R59: 220k; M0805
R60: 1k5; M0805
R61: 10k; M0805
R62: 1k; M0805
R63: 600; M0805
REGS: MA04-1
ROMS: PINHD-1X3; 1X03
S1, S2, S3, S4, S5, S6, S7, S8, S9, S10, S11, S12, S13, S14, S15, S16, S17, S18, S19, S20, S21, S22, S23, S24, S25, S26, S27, S28, S29, S30, S31, S32, S33, S34, S35, S36, S37, S38, S39, S40: DTS-6
SPKR: PINHD-1X2; 1X02
SW: PINHD-1X2; 1X02
T1, T4: BC847; SOT23
T2, T3, T5, T6, T7: 4401; SOT23-BEC
U$1: MC74HC574A; SO20W
U$2: LM1889; SOCKET-18
U$3: MS12ASW30_01; MS12ASG30_01
ULA: ZXULA; DIL40
ULA_RAM: CY62256LL-SNXI; SOJ28/3
VID: PINHD-1X2; 1X02
VPOW: PINHD-1X2; 1X02
Z80A: Z80CPU; DIL40

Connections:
7V4_BATT: BATT.3, BATT.4, J1.1
7V4_SWITCH: J1.2, SW.1, SW.2
12V: C23.1, C24.1, R49.1, REGS.2, U$2.14 (RF_SUPPLY), U$2.15 (SOUND_TANK), U$2.16 (CHROMA_SUPPLY)
A0: 32KRAM.21 (A0), 32K_ROM.11 (A0), 157-1.6 (2B), T7.B, Z80A.30 (A0)
A1: 32KRAM.23 (A1), 32K_ROM.10 (A1), 157-1.3 (1B), Z80A.31 (A1)
A2: 32KRAM.24 (A2), 32K_ROM.9 (A2), 157.6 (2B), Z80A.32 (A2)
A3: 32KRAM.25 (A3), 32K_ROM.8 (A3), 157.3 (1B), Z80A.33 (A3)
A4: 32KRAM.26 (A4), 32K_ROM.7 (A4), 157.13 (4B), Z80A.34 (A4)
A5: 32KRAM.1 (A5), 32K_ROM.6 (A5), 157.10 (3B), Z80A.35 (A5)
A6: 32KRAM.2 (A6), 32K_ROM.5 (A6), 157-1.13 (4B), Z80A.36 (A6)
A7: 32KRAM.3 (A7), 32K_ROM.4 (A7), 157-1.5 (2A), Z80A.37 (A7)
A8: 32KRAM.4 (A8), 32K_ROM.29 (A8), 157-1.2 (1A), D4.C, Z80A.38 (A8)
A9: 32KRAM.5 (A9), 32K_ROM.28 (A9), 157.5 (2A), D3.C, Z80A.39 (A9)
A10: 32KRAM.6 (A10), 32K_ROM.24 (A10), 157.2 (1A), D2.C, Z80A.40 (A10)
A11: 32KRAM.7 (A11), 32K_ROM.27 (A11), 157.14 (4A), D1.C, Z80A.1 (A11)
A12: 32KRAM.8 (A12), 32K_ROM.3 (A12), 157.11 (3A), D5.C, Z80A.2 (A12)
A13: 32KRAM.9 (A13), 32K_ROM.30 (A13), 157-1.14 (4A), D6.C, Z80A.3 (A13)
A14: 32KRAM.10 (A14), D7.C, ULA.36 (A14), Z80A.4 (A14)
A15: D8.C, IC3.1 (I), ULA.37 (A15), Z80A.5 (A15)
CASL: ULA.1 (CASL), ULA_RAM.20 (!CE)
CASS: C10.1, C11.1, D9.C, D10.A, R34.2, R35.1, ULA.28 (CASS/SPKR)
CPU_CLK: R31.2, T3.C, Z80A.6 (CLK)
CPU_INT: Z80A.16 (INT)
CPU_RESET: K10.3, R59.1, Z80A.26 (RESET)
D0: 32KRAM.11 (DQ0), 32K_ROM.13 (D0), R4.1, R11.1, Z80A.14 (D0)
D1: 32KRAM.12 (DQ1), 32K_ROM.14 (D1), R5.1, R9.1, Z80A.15 (D1)
D2: 32KRAM.13 (DQ2), 32K_ROM.15 (D2), R6.1, R10.1, Z80A.12 (D2)
D3: 32KRAM.15 (DQ3), 32K_ROM.18 (D3), R1.1, R12.1, Z80A.8 (D3)
D4: 32KRAM.16 (DQ4), 32K_ROM.19 (D4), R2.1, R13.1, Z80A.7 (D4)
D5: 32KRAM.17 (DQ5), 32K_ROM.20 (D5), R3.1, R14.1, Z80A.9 (D5)
D6: 32KRAM.18 (DQ6), 32K_ROM.21 (D6), R7.1, R15.1, Z80A.10 (D6)
D7: 32KRAM.19 (DQ7), 32K_ROM.22 (D7), R8.1, R16.1, Z80A.13 (D7)
DRAWMWEL: ULA.4 (DRAMWEL), ULA_RAM.27 (!WE)
EAR: JP1.RING (RIGHT), R36.2, R37.1
FCLOCK: IC3.12 (O), U$1.11 (CLOCK)
FLIPCLOCK: U$1.19 (Q0), ULA_RAM.5 (A9)
GND: 32KRAM.14 (GND), 32K_ROM.16 (GND), 157.8 (GND), 157.15 (G), 157-1.8 (GND), 157-1.15 (G), BATT.1, BATT.2, C1.2, C2.2, C3.2, C4.2, C6.2, C7.2, C8.2, C11.2, C14.2, C19.2, C20.2, C21.2, C22.2, C23.2, C24.2, C25.-, C26.2, C27.2, C30.-, D9.A, IC1.7 (GND), IC3.7 (GND), J1.3, JP1.SLEEVE, K10.1, Q1.1, R37.2, R41.2, R42.2, R43.1, R46.2, R50.1, R54.2, R55.2, R56.2, ROMS.1, SPKR.2, T3.E, U$1.1 (OE), U$1.10 (GND), U$2.5 (GND), ULA.40 (GND), ULA_RAM.10 (A14), ULA_RAM.14 (GND), ULA_RAM.22 (!OE), VID.2, VPOW.1, Z80A.29 (GND)
INTL: ULA.12 (INTL)
IOREQL: R64.2, T7.E, ULA.33 (IOREQL)
IORQ: R64.1, Z80A.20 (IORQ)
KEY0: R21.1, S1.1, S10.1, S11.1, S20.1, S21.1, S30.1, S31.1, S40.1, ULA.19 (KB0)
KEY1: R26.1, S2.1, S9.1, S12.1, S19.1, S22.1, S29.1, S32.1, S39.1, ULA.20 (KB1)
KEY2: R27.1, S3.1, S8.1, S13.1, S18.1, S23.1, S28.1, S33.1, S38.1, ULA.23 (KB2)
KEY3: R28.1, S4.1, S7.1, S14.1, S17.1, S24.1, S27.1, S34.1, S37.1, ULA.24 (KB3)
KEY4: R29.1, S5.1, S6.1, S15.1, S16.1, S25.1, S26.1, S35.1, S36.1, ULA.26 (KB4)
MIC: C9.2, JP1.TIP (LEFT)
MREQ: IC1.2 (I1), IC1.4 (I0)
MREQL: ULA.38 (MREQL), Z80A.19 (MREQ)
unnamed: 32K_ROM.25 (!OE), R63.2
unnamed: R4.2, ULA.18 (D0), ULA_RAM.11 (DQ0)
unnamed: R5.2, ULA.21 (D1), ULA_RAM.12 (DQ1)
unnamed: R6.2, ULA.22 (D2), ULA_RAM.13 (DQ2)
unnamed: R1.2, ULA.25 (D3), ULA_RAM.15 (DQ3)
unnamed: R2.2, ULA.27 (D4), ULA_RAM.16 (DQ4)
unnamed: R3.2, ULA.29 (D5), ULA_RAM.17 (DQ5)
unnamed: R7.2, ULA.30 (D6), ULA_RAM.18 (DQ6)
unnamed: R8.2, ULA.31 (D7), ULA_RAM.19 (DQ7)
unnamed: U$1.13 (Q6), ULA_RAM.21 (A0)
unnamed: U$1.14 (Q5), ULA_RAM.23 (A1)
unnamed: U$1.15 (Q4), ULA_RAM.24 (A2)
unnamed: U$1.16 (Q3), ULA_RAM.26 (A4)
unnamed: U$1.17 (Q2), ULA_RAM.2 (A6)
unnamed: 157.4 (1Y), R17.1
unnamed: Q1.3 (2), ULA.39 (OSC)
unnamed: 157.7 (2Y), R18.1
unnamed: U$1.18 (Q1), ULA_RAM.3 (A7)
unnamed: 157-1.4 (1Y), R19.1
unnamed: 157-1.7 (2Y), R20.1
unnamed: C5.2, R30.1, T3.B
unnamed: C12.2, R38.1, T4.1 (B)
unnamed: D10.C, T2.B
unnamed: C9.1, R35.2
unnamed: 157-1.12 (4Y), R22.2
unnamed: D1.A, S1.4, S2.4, S3.4, S4.4, S5.4
unnamed: D2.A, S11.4, S12.4, S13.4, S14.4, S15.4
unnamed: R60.2, Z80A.24 (WAIT)
unnamed: D3.A, S21.4, S22.4, S23.4, S24.4, S25.4
unnamed: D4.A, S31.4, S32.4, S33.4, S34.4, S35.4
unnamed: 157.1 (A/B), 157-1.1 (A/B), R25.1
unnamed: D5.A, S6.4, S7.4, S8.4, S9.4, S10.4
unnamed: D6.A, S16.4, S17.4, S18.4, S19.4, S20.4
unnamed: 157.9 (3Y), R23.2
unnamed: D7.A, S26.4, S27.4, S28.4, S29.4, S30.4
unnamed: D8.A, S36.4, S37.4, S38.4, S39.4, S40.4
unnamed: 157.12 (4Y), R24.2
unnamed: C13.2, R39.1, T1.1 (B)
unnamed: C10.2, R36.1
unnamed: C14.1, R40.2, U$2.3 (CHROMA_BIAS)
unnamed: C15.1, R48.1, T4.3 (C)
unnamed: 32K_ROM.31 (A14), ROMS.2
unnamed: C16.1, R47.1, T1.3 (C)
unnamed: R49.2, U$2.12 (VIDEO_INPUT)
unnamed: C17.1, U$2.1 (CHROMA_LEAD)
unnamed: C17.2, C18.1, R43.2
unnamed: C19.1, R44.2, U$2.18 (CHROMA_LAG)
unnamed: C18.2, Q2.2, R44.1
unnamed: R45.2, R46.1, U$2.17 (CHROMA_OSC)
unnamed: C22.1, R47.2, U$2.4 (U_INPUT)
unnamed: C20.1, Q2.1, R45.1
unnamed: C21.1, R48.2, U$2.2 (V_INPUT)
unnamed: C29.+, R51.1, U$2.13 (CHROMA_SUB)
unnamed: R61.2, Z80A.17 (NMI)
unnamed: C25.+, C26.1, C27.1, R51.2, R52.1, R53.1, R58.1, T5.C
unnamed: C29.-, R53.2, T5.B, T6.C
unnamed: R54.1, T6.E
unnamed: R62.2, Z80A.25 (BUSRQ)
unnamed: R56.1, R57.2, R58.2, T6.B
unnamed: REGS.3, REGS.4, U$3.3 (S), VPOW.2
PHICPU: C5.1, R30.2, R32.2, ULA.32 (PHICPU)
RAM_CE: 32KRAM.20 (!CE), IC3.2 (O)
RAM_OE: 32KRAM.22 (!OE), IC1.3 (O)
RAM_WE: 32KRAM.27 (!WE), IC1.6 (O)
RASL: IC3.13 (I), R25.2, ULA.35 (RASL)
READ: IC1.1 (I0), ULA.3 (RDL), Z80A.21 (RD)
ROM_CE: 32K_ROM.23 (!CE)
ROM_CS: R63.1, ULA.34 (ROMCSL)
SPEAKER: SPKR.1, T2.E
URAMA0: R20.2, U$1.6 (D4), ULA.5 (DMA0), ULA_RAM.8 (A12)
URAMA1: R19.2, U$1.3 (D1), ULA.6 (DMA1), ULA_RAM.4 (A8)
URAMA2: R18.2, U$1.8 (D6), ULA.7 (DMA2), ULA_RAM.25 (A3)
URAMA3: R17.2, U$1.5 (D3), ULA.8 (DMA3), ULA_RAM.6 (A10)
URAMA4: R24.1, U$1.4 (D2), ULA.9 (DMA4), ULA_RAM.7 (A11)
URAMA5: R23.1, U$1.2 (D0), ULA.10 (DMA5), ULA_RAM.9 (A13)
URAMA6: R22.1, U$1.7 (D5), ULA.11 (DMA6), ULA_RAM.1 (A5)
VCC: 32KRAM.28 (VCC), 32K_ROM.2 (VPP), 32K_ROM.32 (VCC), 157.16 (VCC), 157-1.16 (VCC), C1.1, C2.1, C3.1, C4.1, C6.1, C8.1, C30.+, IC1.14 (VCC), IC3.14 (VCC), R9.2, R10.2, R11.2, R12.2, R13.2, R14.2, R15.2, R16.2, R21.2, R26.2, R27.2, R28.2, R29.2, R31.1, R32.1, R33.2, R34.1, R38.2, R39.2, R40.1, R52.2, R59.2, R60.1, R61.1, R62.1, REGS.1, ROMS.3, T1.2 (E), T2.C, T4.2 (E), T7.C, U$1.20 (VCC), ULA.14 (VCC), ULA_RAM.28 (VCC), Z80A.11 (VCC)
VCC/VAN: C7.1, R33.1, ULA.13 (VCC/VAN)
VIDEO: R55.1, T5.E, VID.1
VID_U: C16.2, R42.1, ULA.15 (U)
VID_V: C15.2, R41.1, ULA.16 (V)
VID_YL: C12.1, C13.1, R50.2, R57.1, ULA.17 (YL)
WRITE: IC1.5 (I1), ULA.2 (WRL), Z80A.22 (WR)

Board: 2 copper layers, 174 parts (3 on the bottom side), 128 nets, no tracks yet.

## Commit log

2015-11-03 initial comit
    [MCP73833_QFN_v1.0.brd, MCP73833_QFN_v1.0.csv, MCP73833_QFN_v1.0.sch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]
2015-11-03 BOM added
    [zx_kit_BOM.csv]

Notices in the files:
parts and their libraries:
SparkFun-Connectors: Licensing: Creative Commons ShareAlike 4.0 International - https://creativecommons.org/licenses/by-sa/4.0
